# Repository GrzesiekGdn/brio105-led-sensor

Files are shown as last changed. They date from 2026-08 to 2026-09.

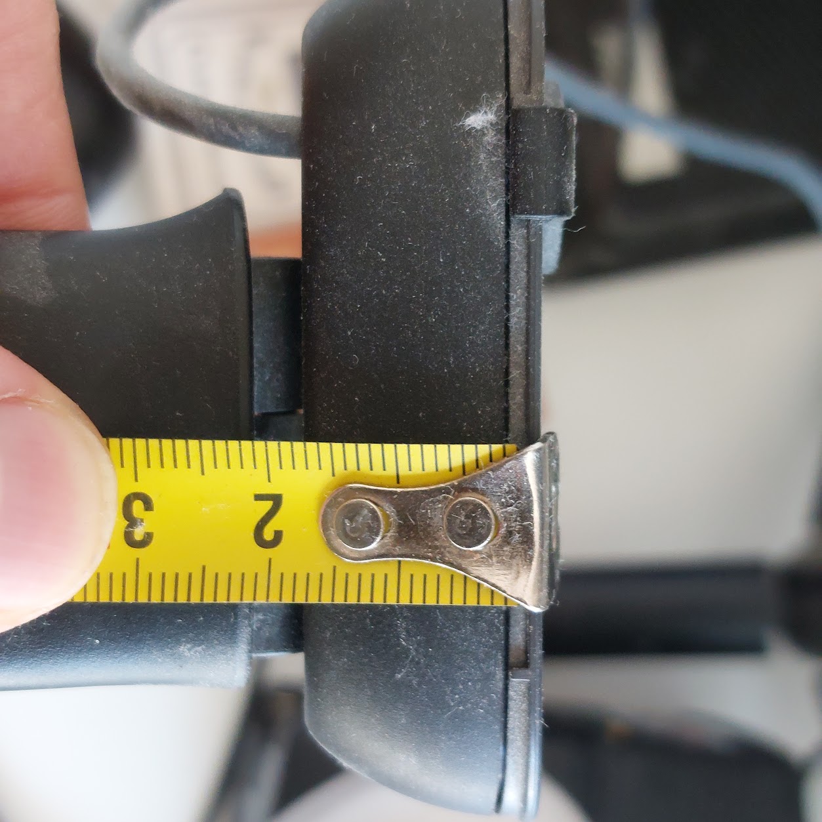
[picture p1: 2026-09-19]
hardware/clip/photos/20260829_162636.jpg

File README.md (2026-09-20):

# brio105-led-sensor

A 3D-printable clip and sensor pod that detect when a **Logitech Brio 105** webcam is in use — by *watching the camera's own activity LED*, not by asking the operating system.

---

## 🎯 Why

The obvious way to know whether your webcam is running is to ask the OS. That is what
[micam-watcher](https://github.com/GrzesiekGdn/micam-watcher) does, and if you can install
your own software on the machine, it is the better answer — see
[Alternative](#-alternative-if-you-can-install-software) below.

But on a **corporate / locked-down machine** you often cannot:

- no admin rights, no installing a background service
- no writing to the registry, no systemd user units
- endpoint protection that flags anything watching `/dev/video*` or camera registry keys
- and it may simply be against your employer's IT policy

The camera itself has no such restriction. Every Brio 105 lights a small LED whenever the
sensor is streaming — that signal is generated by the camera's own firmware, it is always
correct, and reading it requires touching nothing on the host at all.

So: clip a phototransistor over that LED, shroud it from ambient light, and read it with a
microcontroller that has no connection to the work machine whatsoever. The corporate laptop
never knows the sensor exists — no software installed, no policy violated, no privileged
access needed. It works with any camera and any OS, since the only thing being observed is
a lamp.

Typical use: turn on a "busy" light outside the room, or set a Home Assistant presence flag,
while you are on a call.

---

## 📐 Where the camera geometry came from

The parts have to fit the camera closely — a shroud that leaks ambient light is useless — so
the design is built on a real mesh of the camera, not on guesswork.

1. **No public CAD model exists** for the Brio 105. GrabCAD, STLFinder and Printables only
   carry mounts for other Brio models, and Logitech publishes no CAD for this one.
2. **Logitech's own product page does** ship a 3D model, though — the *"view in your room"* /
   AR preview that lets you rotate the webcam in the browser. That viewer loads a plain glTF
   binary asset, served from Logitech's CDN:

   ```
   https://resource.logitech.com/content/dam/logitech/en/ar-models/webcams/brio-100/brio-100-graphite-webcams-ar-360.glb
   ```

   (there is a matching `…-usdz-360.usdz` for iOS AR).
3. **The `.glb` was parsed by hand.** No mesh tooling was available in the environment
   (`trimesh`, `pygltflib`, Blender, assimp — none installable), so the container was
   unpacked directly with stdlib Python `struct`/`json`: read the glTF chunk table, walk the
   accessors/buffer views, pull the vertex and index arrays out of the binary chunk, and
   write the meshes back out as STL. Those exports are kept in [hardware/reference/](hardware/reference/):
   - `brio100-camera-head.stl` — the camera body itself
   - `brio100-monitor-clip.stl` — the monitor hanger, kept for context
4. **The mesh was measured by rasterization.** Again with no CAD library available, the STL
   was rendered into depth-map slices with a small custom Z-buffer renderer (Python + PIL)
   and scanned for features: the lens shows up as a ~10 mm circular recess at
   `(X=-15.8, Y=31.0)`, and the front/back faces around the LED are genuinely flat and
   parallel, ~17.9 mm apart. Those coordinates are what the `.scad` files are built from.
5. **Cross-checked against the physical camera** with a tape measure — bezel diameter, LED
   offset from the lens, housing depth. The mesh numbers and the hand measurements agree —
   except the first housing-depth reading, which came out about 1 mm short (see
   [Clip versions](#-clip-versions)).

You can see the fit yourself: open [hardware/clip/brio105-sensor-clip-v1.2.scad](hardware/clip/brio105-sensor-clip-v1.2.scad) in
OpenSCAD with `show_reference = true` and the reference mesh is `import()`-ed in ghost mode,
in the same coordinate frame, with the clip sitting on it.

### ⚠️ The one unverified assumption

The AR asset Logitech publishes is for the **Brio 100**, not the **105** — no Brio 105 AR or
CAD model could be found anywhere. Product photos strongly suggest the two share a housing
and mould, but this has **not** been confirmed. Check a printed part against your real Brio
105 before trusting the fit. Other open points are listed under
`STILL UNVERIFIED` in the `.scad` header.

---

## 📦 What is here

| File | What it is |
|---|---|
| `hardware/clip/` | The spring clip ("hairpin" style) that grips the flat front/back faces beside the LED — v1.2 (latest), v1.1 and v1.0, each `.scad` + `.stl`, plus the tape-measure photo the fit is based on. See its [README](hardware/clip/README.md) |
| `hardware/enclosure/` | Desk enclosure for the Seeed XIAO ESP32-C6 — snap-together tray and lid, holding the board, the 10k load resistor and the sensor-cable junction. Tray and lid as separate STLs; `part = "both"` in the `.scad` puts them on one plate. Also holds the XIAO reference model, `include`-ed as a ghost preview. See its [README](hardware/enclosure/README.md) |
| `hardware/pod/` | Alternative attachment: a magnetic sensor pod plus a stick-on anchor. Holds the TEPT4400 and acts as the light shroud. Rotationally keyed so it can only re-attach the right way round. |
| `hardware/reference/` | The STL meshes extracted from Logitech's AR asset (reference only — not printable parts) |
| `hardware/wiring/` | [Wiring and first tests](hardware/wiring/README.md) — the circuit, the two wiring layouts and the no-solder tests for the board, with the drawings in `hardware/wiring/img/` |
| `firmware/` | [Toolchain and tests](firmware/README.md) — what to install, how to run the three board tests, and where the Arduino functions come from |

**Sensor:** TEPT4400 phototransistor. **Print:** matte black PETG or ABS — glossy filament
reflects stray light down the tunnel and defeats the shroud. Per-part print notes are in each
`.scad` header.

---

## 🧬 Clip versions

Three versions live in [hardware/clip/](hardware/clip/README.md). They are geometrically
close, but they reach their fit in different ways, and v1.2 rebuilt the spring so the grip no
longer depends on the exact housing thickness — the earlier two flipped between *cracks on
fitting* and *falls off* with half a millimetre of error.

Prints of v1.1 and v1.2 are on order for a test fit; neither is confirmed yet. The clip's own
README has the full comparison and the print orientation, which matters more than the
material on this part.

---

## 🧰 Controller enclosure

The clip holds the phototransistor on the camera; the other end of the cable lives in a
free-standing desk box — a bare XIAO ESP32-C6, the 10k load resistor and the cable junction,
with USB-C plugged in for power. Two snap-together printed parts, built on Seeed's own KiCad
geometry rather than on a published drawing, since their wiki and datasheet disagree about the
board size.

See [hardware/enclosure/](hardware/enclosure/README.md), and
[hardware/wiring/](hardware/wiring/README.md) for what goes inside it.

---

## 🗺️ Roadmap

- [x] **1. Reference geometry** — extract and measure the camera model
- [ ] **2. Clip** — prints of v1.1 and v1.2 ordered; test-fit both on the real camera, keep
      the better one, dial in the spring interference
- [ ] **3. Phototransistor** — mount the TEPT4400 in the clip/pod, wire it to a Seeed XIAO
      ESP32-C6 ([wiring and first tests](hardware/wiring/README.md)) in its
      [enclosure](#-controller-enclosure),
      calibrate the threshold that separates "LED on" from ambient light
- [ ] **4. Software** — firmware that debounces the reading and sends the state to
      [Home Assistant](https://www.home-assistant.io/) over Zigbee (built into the XIAO ESP32-C6)
      or an HTTP webhook / MQTT, so it can drive an automation: a busy light, a lamp, a
      presence flag

---

## 🔌 Alternative: if you *can* install software

If the machine is yours, skip the hardware entirely.
**[micam-watcher](https://github.com/GrzesiekGdn/micam-watcher)** is a small cross-platform Go
service that detects camera *and* microphone activity from the OS itself — `lsof` on
`/dev/video*` and `pactl` on Linux, registry keys on Windows — and POSTs to the same kind of
Home Assistant webhook. No printing, no soldering, and it covers the microphone too, which a
camera LED cannot tell you about.

| | this project | micam-watcher |
|---|---|---|
| Needs software on the monitored machine | no | yes |
| Works on a locked-down / corporate machine | yes | usually not |
| Detects camera | yes | yes |
| Detects microphone | no | yes |
| Camera / OS specific | fits the Brio 105 housing | Linux & Windows |
| Effort | print, wire, calibrate | install a service |

---

## 📄 License

Copyright © 2026 Grzegorz Danowski. Two licenses, one per medium:

| What | License | |
|---|---|---|
| **Hardware designs** — `.scad`, `.stl`, `.3mf` | [CC-BY-SA 4.0](LICENSE) | Remix and sell them freely, including commercially — but credit this project and release your modified designs under the same license. |
| **Software** — future Arduino firmware and tooling | [MIT](LICENSE-CODE) | Do anything you like, just keep the copyright notice. |

The meshes in [hardware/reference/](hardware/reference/) are **not covered by either** — they are extracted from
Logitech's own published AR asset and remain Logitech's. They are included solely as a
dimensional reference for checking fit, and are not printable parts.

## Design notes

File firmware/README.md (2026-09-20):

# Firmware

Nothing final lives here yet. The sketches in [`tests/`](tests/) exist to prove the XIAO
ESP32-C6 works — and that it isn't faulty — before anything gets soldered. The real firmware
(read the sensor, debounce it, report to Home Assistant over Zigbee) is roadmap step 4.

The wiring and what each test proves are in
[hardware/wiring/](../hardware/wiring/README.md). This page is about the toolchain: what to
install, how to run the sketches, and where the functions in them come from.

---

## What to install

Either route installs the same package. The sketches here were compiled and run against
**esp32 core 3.3.12**.

### Arduino IDE 2

1. Install the IDE from [arduino.cc](https://www.arduino.cc/en/software).
2. **Tools → Board → Boards Manager**, search `esp32`, install **esp32 by Espressif
   Systems**, version **3.0 or newer**. Version 2.x does not know the C6. If it isn't listed,
   add this under **File → Preferences → Additional boards manager URLs**:
   ```
   https://raw.githubusercontent.com/espressif/arduino-esp32/gh-pages/package_esp32_index.json
   ```
3. **Tools → Board → esp32 → XIAO_ESP32C6**
4. **Tools → Port → /dev/ttyACM0**
5. Open a sketch, click **Upload**, then **Tools → Serial Monitor** at **115200**.

On Linux your user must be in the `dialout` group to open the port:

```sh
sudo usermod -aG dialout $USER     # then log out and back in
```

### arduino-cli

Same package, no IDE:

```sh
arduino-cli core update-index \
  --additional-urls https://raw.githubusercontent.com/espressif/arduino-esp32/gh-pages/package_esp32_index.json
arduino-cli core install esp32:esp32@3.3.12

# compile only - needs no board attached
arduino-cli compile -b esp32:esp32:XIAO_ESP32C6 firmware/tests/test2_alive

# compile and upload
arduino-cli compile -u -p /dev/ttyACM0 -b esp32:esp32:XIAO_ESP32C6 firmware/tests/test2_alive

# watch the output
arduino-cli monitor -p /dev/ttyACM0 -c baudrate=115200
```

---

## Running the tests

Upload one, watch the serial output, move on. Full procedure, expected results and the
keep-or-return table are in [hardware/wiring/](../hardware/wiring/README.md).

| Sketch | What it proves | What a working board printed |
|---|---|---|
| [`tests/test2_alive`](tests/test2_alive/test2_alive.ino) | Uploading works; processor, flash and USB messages work | `alive \| ESP32-C6 rev 2 \| 160 MHz \| flash 4 MB \| uptime 7 s`, and the yellow LED blinks |
| [`tests/test3_radio`](tests/test3_radio/test3_radio.ino) | The 2.4 GHz radio and antenna work — the same ones Zigbee uses | `3 networks found`, nearest at `-62 dBm` |
| [`tests/test4_adc`](tests/test4_adc/test4_adc.ino) | The analogue input the sensor will use (A0) works | `raw 676 586 mV` floating; ≈0 wired to GND, ≈4095 wired to 3V3 |

If an upload fails, put the board in download mode: hold **B** (BOOT), tap **R** (RESET),
release **B**, upload again, then tap **R** to run.

---

## Where do these functions come from?

A fair question, because an `.ino` file has almost no `#include` lines and still calls
`pinMode` and `Serial`. Three things are happening.

**1. The `.ino` is not quite C++ yet.** Before compiling, the IDE (or arduino-cli)
concatenates the sketch, adds `#include <Arduino.h>` at the top, and generates forward
declarations for your functions — which is why `loop()` can call a function defined below it.
The result is an ordinary `.cpp`.

**2. There is a `main()`, you just don't write it.** The core provides it. Simplified, it
calls `setup()` once and then `loop()` forever. On the ESP32 that loop runs inside a FreeRTOS
task, so `delay()` yields to the scheduler rather than burning cycles — which matters later,
when Wi-Fi or Zigbee needs time of its own.

**3. `Arduino.h` pulls in the rest.** On this core it includes `esp32-hal.h`,
`HardwareSerial.h` and `Esp.h`, and those bring everything the sketches use except `WiFi`:

| What the sketch calls | Where it is declared | `#include` needed? |
|---|---|---|
| `pinMode`, `digitalWrite`, `HIGH`, `LOW`, `OUTPUT` | `cores/esp32/esp32-hal-gpio.h` | no |
| `delay`, `millis` | `cores/esp32/esp32-hal.h` | no |
| `analogRead`, `analogReadMilliVolts` | `cores/esp32/esp32-hal-adc.h` | no |
| `Serial`, `Serial.begin`, `.println`, `.printf` | `cores/esp32/HardwareSerial.h` | no |
| `ESP.getChipModel()`, `.getFlashChipSize()` … | `cores/esp32/Esp.h` | no |
| `WiFi.scanNetworks()`, `WiFi.SSID(i)` … | `libraries/WiFi/src/WiFi.h` | **yes** — `#include <WiFi.h>` |

On this machine that is
`~/.arduino15/packages/esp32/hardware/esp32/3.3.12/…` — worth opening if you want to see how
thin most of these wrappers are.

### Two details specific to this board

**`Serial` is not a serial port here.** `HardwareSerial.h` contains:

```cpp
#define Serial HWCDCSerial    // when the board is built with cdc_on_boot=1
```

`XIAO_ESP32C6` sets `build.cdc_on_boot=1` by default, so `Serial` is the USB connection built
into the chip, not a UART on pins D6/D7. That is why the messages arrive over the same cable
that powers and flashes the board, and why the baud rate you pick is irrelevant — USB has no
baud rate. The Serial Monitor still asks for one; anything works.

**Arduino here is a layer, not the bottom.** `arduino-esp32` 3.x sits on top of Espressif's
own SDK, ESP-IDF 5.x. `analogRead` is a wrapper around the IDF ADC driver, `WiFi` around
`esp_wifi`. When Arduino doesn't expose something — precise ADC calibration, or Zigbee — you
can call IDF functions directly from the same sketch, because it is all one binary.

### Which of these are "libraries"?

Only one, strictly. `WiFi` is a library: a folder under `libraries/` in the core, with its own
`src/`, and it needs an `#include`. Everything else — `pinMode`, `delay`, `Serial`, `ESP` — is
the **core** itself, compiled into every sketch whether you use it or not. Nothing here comes
from the Library Manager, and these three sketches install no third-party dependencies at all.

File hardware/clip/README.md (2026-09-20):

# Camera clip

A spring clip ("hairpin" style) that grips the flat front and back faces beside the Brio 105's
activity LED and holds the TEPT4400 against it. Front and back are parallel there, so it
clamps by flexing, not by hooking a corner.

| File | What it is |
|---|---|
| `brio105-sensor-clip-v1.2.scad` / `.stl` | **Latest.** |
| `brio105-sensor-clip-v1.1.scad` / `.stl` | Earlier version, to be test-fitted against v1.2 |
| `brio105-sensor-clip-v1.0.scad` / `.stl` | First version, kept for comparison |
| `photos/` | Tape-measure photo of the housing depth that v1.2's fit is based on |

Open any version in OpenSCAD with `show_reference = true` and the camera mesh from
[`../reference/`](../reference/) is `import()`-ed in ghost mode, in the same coordinate frame,
with the clip sitting on it.

---

## Versions

All three share the same coordinate frame, lens and LED positions, and TEPT4400 bore, so
they are directly comparable in OpenSCAD.

> **Not yet tested.** Prints of v1.1 and v1.2 have been ordered for a test fit on the real
> Brio 105. Until they arrive and have been tried, neither is confirmed — this section will
> name the one that fits best.

| Version | Relaxed jaw gap | What changed |
|---|---|---|
| **v1.0** — proposed by Claude | 17.3 mm | First design, built on the reference mesh: 17.9 mm housing minus 0.6 mm interference. 12 mm tall jaws. |
| **v1.1** — revised with ChatGPT | 17.3 mm | Jaws raised to 14 mm. Fit rebased on a tape measurement of the real camera: 17.0 mm plus 0.3 mm clearance. Same gap as v1.0, opposite reasoning — v1.0 meant it to grip, v1.1 to slide on freely. |
| **v1.2** — also by Claude | 16.2 mm | Spring redesigned so the fit no longer depends on the exact housing thickness. |

**Why v1.2 exists.** v1.0 and v1.1 are geometrically nearly the same part, and share two
problems:

- **The spring was not a spring.** The back jaw wrapped the camera's rounded end, which left
  the "bridge" as a solid block and put all the flex in a stiff 2.5 mm jaw (~48 N/mm). A
  ±0.5 mm error in housing thickness flipped it between *cracks on fitting* and *falls off*.
  v1.2 uses a flat back jaw and makes a thin 1.5 mm bridge the flexure (~3.3 N/mm), so it
  holds across the whole plausible range of 17.0–18.6 mm without over-stressing.
- **The 17.0 mm reading was probably ~1 mm short.** The tape's end hook has about 1 mm of
  slide in its rivet slot. Measured off the photo in [`photos/`](photos/), the housing is
  ~18.2 mm — consistent with the reference mesh's 17.86 mm.

v1.2 also moves the jaw's near edge 0.6 mm back from the lens rim (v1.0/v1.1 sat just over
it), lets only contact ribs touch the housing, and adds a 5 × 3 mm funnel in front of the
sensor, so the LED can be off its assumed position by ±2 mm along the bar and ±1.5 mm
vertically and still be seen.

---

## Printing

**Orientation matters more than material here.** Lay the C-shape flat on the bed as a
17 × 27 mm footprint and build 14 mm upward — that is the model's **Y axis vertical**. The
whole flexure is then one constant cross-section: no supports, no bridging, and the bending
stress runs along the extrusion paths instead of across layer boundaries. The obvious
alternative, bore pointing up, puts the bridge's tensile stress normal to the layers, which
is how a spring like this fails months later.

Suggested: 4 perimeters, 40%+ infill, and a brim for the thin first-layer outline. Use matte
black filament — glossy reflects stray light down the tunnel and defeats the shroud. v1.2's
header argues for PLA here, as the stiffest common option; PETG works but creeps more under
sustained load.

The full rationale, the measurements behind every number, and a batch of test prints for the
two remaining unknowns are in the `.scad` headers.

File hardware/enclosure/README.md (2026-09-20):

# Controller enclosure

The clip or the pod holds the phototransistor on the camera; the other end of the cable has
to live somewhere too. This is a free-standing desk box for that end: a bare XIAO ESP32-C6,
the single 10k load resistor for the TEPT4400, and the junction where the sensor cable is
soldered on. USB-C stays plugged in for power, and the onboard ceramic antenna radiates
through the plastic — so nothing but the sensor cable leaves the box.

| File | What it is |
|---|---|
| `xiao-esp32c6-enclosure-v1.scad` | The enclosure. `part = "tray"`, `"lid"` or `"both"` — `"both"` puts them on one plate |
| `xiao-esp32c6-enclosure-v1-tray.stl` / `-lid.stl` | The two printed parts |
| `xiao-esp32c6-board.scad` | Reference model of the XIAO itself, `include`-ed as a ghost preview — not a printable part |

It is built the same way as the clip: not on a published drawing, but on the real geometry.
Seeed's wiki and their own datasheet disagree about the board size (17.8 vs 17.5 mm), and
neither publishes PCB thickness, component heights or LED positions, so
[`xiao-esp32c6-board.scad`](xiao-esp32c6-board.scad) is generated straight from Seeed's KiCad
PCB file instead. Open the enclosure in OpenSCAD with `show_board = true` and the board sits
in the box in its real position, the same trick as `show_reference` on the clip.

> **Not yet tested.** The tray and lid went to the print shop in the same order as the v1.1
> and v1.2 camera clips, so they arrive together and can be test-fitted in one go.

---

## Printing

Tray open side up, lid top face **down**. Neither needs support. PETG is preferred over PLA:
the snap arms work at about 1.6 % strain, which PLA survives but does not forgive.

They snap together with four full-depth cantilever arms — no glue, opened again with a
fingernail or a spudger at the pry notch. The activity LED shows through a light bar: a blind
pocket that leaves a 0.5 mm skin, so the lid is an unbroken surface until the LED lights up.

After a CGAL render (F6), `Volumes` should be **2** for a tray or lid on its own and **3** for
both parts together — that is the solid(s) plus the outside. A larger number means a feature
has come loose as a separate body. The `.scad` header carries the same treatment for the
snap-arm strain budget: change the wall, floor or plug clearances and re-read the strain
figure it echoes.

---

## Wiring

What goes inside the box — the resistor, the junction and the two-wire cable to the sensor —
is in [hardware/wiring/](../wiring/README.md), together with the tests that check the XIAO
itself before anything is soldered.

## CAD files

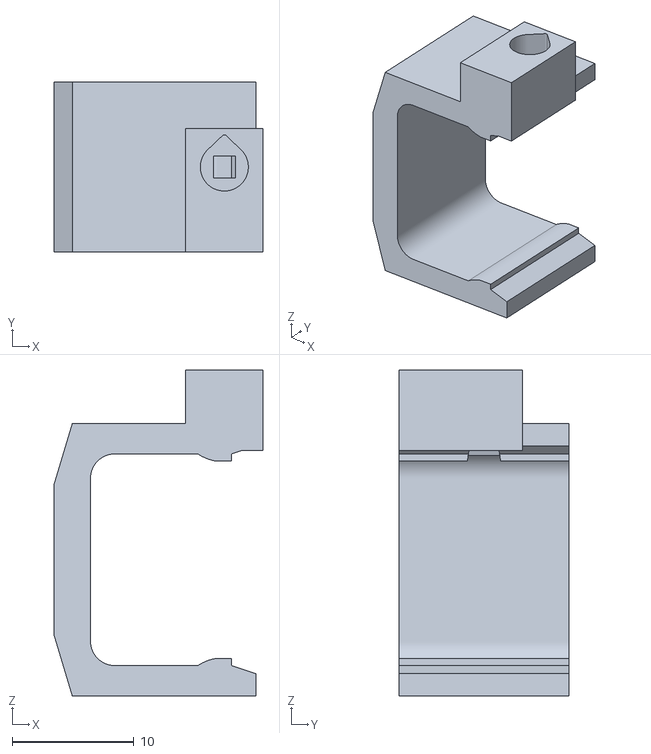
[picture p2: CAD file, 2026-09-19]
hardware/clip/brio105-sensor-clip-v1.2.stl
17.2 x 14.0 x 26.8

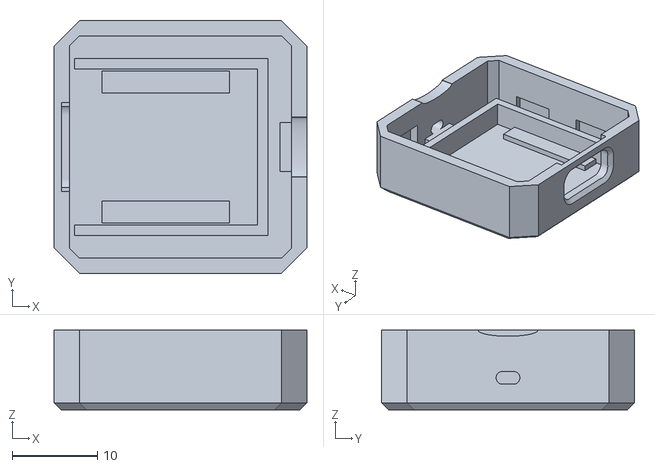
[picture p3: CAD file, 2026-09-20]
hardware/enclosure/xiao-esp32c6-enclosure-v1-tray.stl
29.8 x 29.8 x 9.35

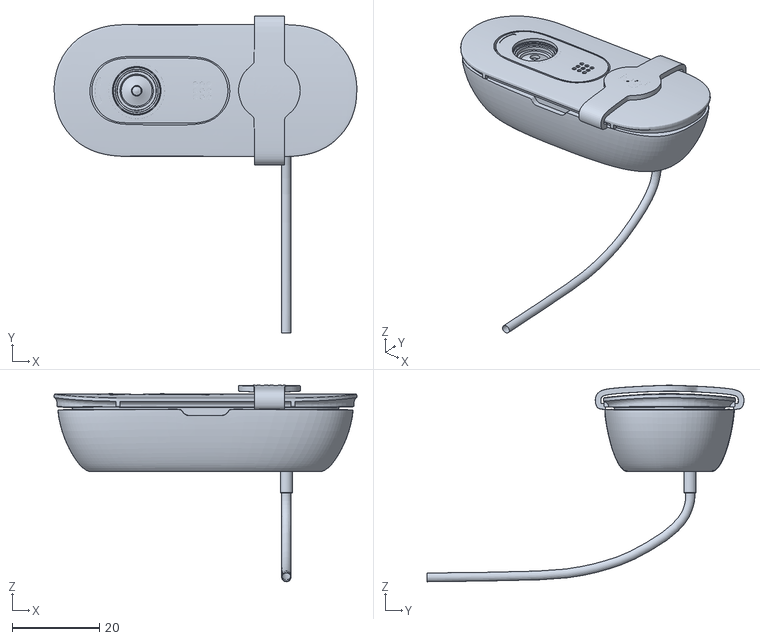
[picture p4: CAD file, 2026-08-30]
hardware/reference/brio100-camera-head.stl
69.5 x 72.8 x 45.1

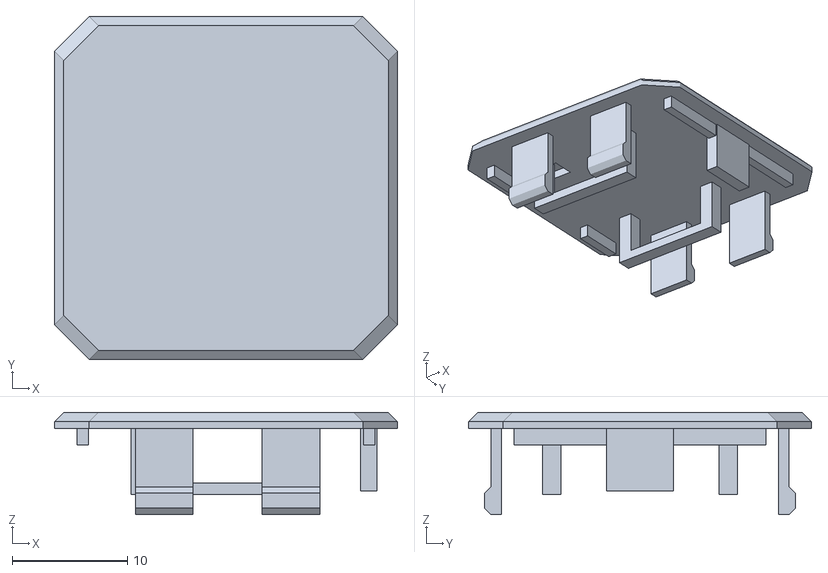
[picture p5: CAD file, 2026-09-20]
hardware/enclosure/xiao-esp32c6-enclosure-v1-lid.stl
29.8 x 29.8 x 8.85

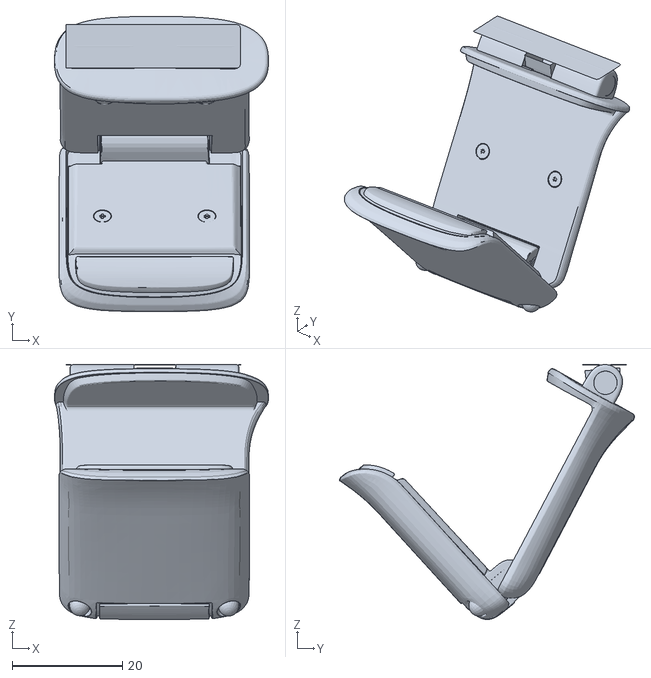
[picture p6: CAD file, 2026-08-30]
hardware/reference/brio100-monitor-clip.stl
38.9 x 53.6 x 46.3

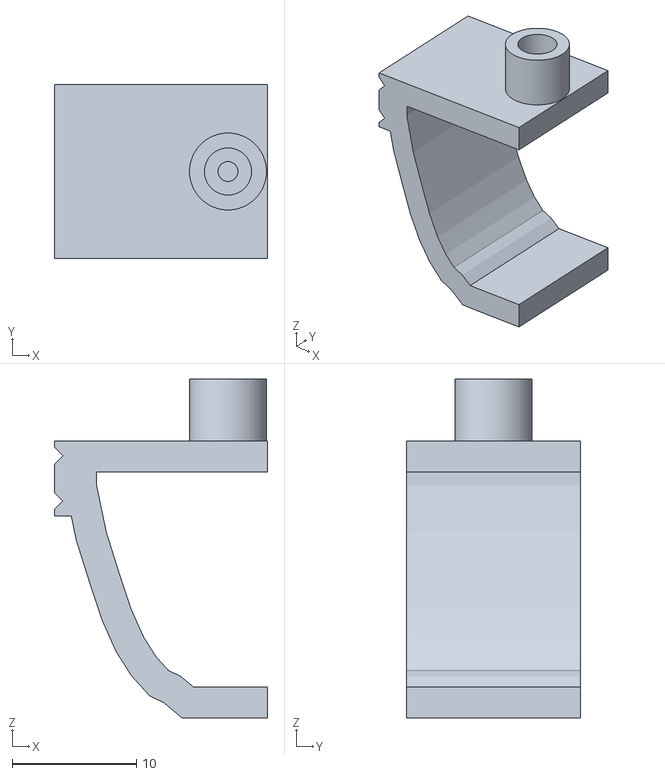
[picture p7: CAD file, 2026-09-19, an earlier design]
hardware/clip/brio105-sensor-clip-v1.1.stl
17.2 x 14.0 x 27.3

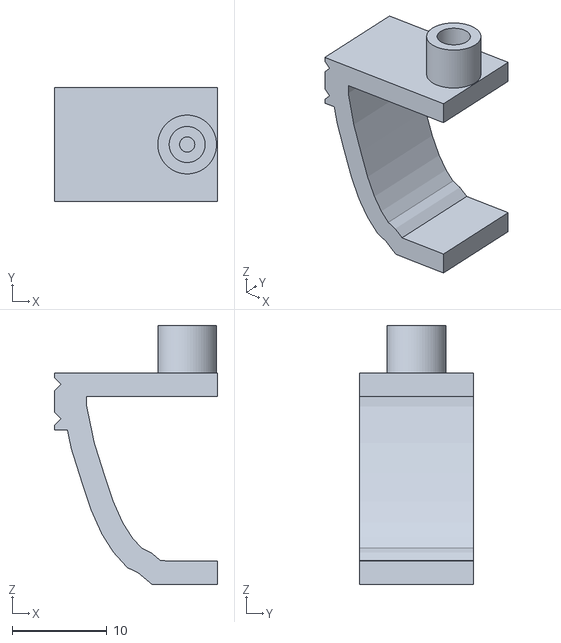
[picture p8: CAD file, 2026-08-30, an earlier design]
hardware/clip/brio105-sensor-clip-v1.0.stl
17.2 x 12.0 x 27.3

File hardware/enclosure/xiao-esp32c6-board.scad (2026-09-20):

// ============================================================
// XIAO ESP32-C6 REFERENCE BOARD MODEL
//
// NOT a downloaded mesh. Seeed only publish their 3D model via GrabCAD,
// which needs a login, so this is generated directly from their own
// KiCad design files instead:
//   XIAO_ESP32_C6_v1.0_SCH&PCB_260114.zip -> "XIAO ESP32 C6.kicad_pcb"
//   (linked from wiki.seeedstudio.com/xiao_esp32c6_getting_started)
// For fitting a case that is better than a mesh: it gives the
// authoritative position of every part, so clearances can be checked by
// intersection instead of by eye.
//
// EXACT, straight out of the PCB file:
//   - outline 20.955 x 17.780mm (Edge.Cuts) - so Seeed's wiki figure of
//     17.8 is right and their datasheet's 17.5 is wrong
//   - thickness 1.6mm (board stackup)
//   - X, Y, rotation and pad/courtyard footprint of all 81 parts
//   - every part is on the front. The underside really is flat, which is
//     what lets the tray sit the board on an 0.8mm standoff.
// INFERRED:
//   - part HEIGHTS. KiCad stores no Z. Taken from footprint names that
//     state one (ANT2P-5.2x2x1.1MM -> 1.1) and from package convention
//     otherwise (0402 -> 0.5, QFN -> 0.9, USB-C -> 3.26). Treat Z as
//     indicative and X/Y as measured.
//   - XY extents are the pad + courtyard + fab envelope, so for most
//     parts they are slightly larger than the plastic body. That is the
//     useful direction to err.
//   - USB1 is the exception and is hand-set from its COURTYARD, X
//     15.15..22.55 by Y 4.29..13.49. That courtyard is 7.40 deep against
//     a 7.35mm body, i.e. drawn on the body with no margin, so it is the
//     honest outline. Note what it means: the front face sits at 22.55
//     against a board edge at 20.955, so the receptacle OVERHANGS the
//     board by 1.60mm. Any case that pushes the board up to the wall has
//     to make room for that. Its F.Fab outline is not used - that is the
//     plug keepout, floating 1.2mm off the board edge.
//
// FRAME: origin at the board corner, X 0..20.955 with the USB-C end at
// HIGH X, Y 0..17.780, Z 0 at the underside.
// ============================================================

pcb_len   = 20.955;
pcb_wid   = 17.780;
pcb_thick = 1.600;
pcb_r     = 1.905;   // corner radius, from the four Edge.Cuts arcs:
                     // e.g. start(-10.414,-6.985) mid(-9.856,-8.332)
                     // end(-8.509,-8.89), centre (-8.509,-6.985)

// OPTIONAL REAL MESH
// ------------------
// Seeed's own 3D model exists but is not machine-downloadable: GrabCAD
// and Marathon-OS want a login and Printables returns 403 to anything but
// a browser. If you fetch one yourself, drop the file next to this one and
// put its name here - it is then used instead of the generated body, in
// the same frame. Nothing else needs to change.
//   https://www.printables.com/model/1338408-3d-model-for-seeed-studio-xiao-esp32c6  (Seeed's own)
//   https://grabcad.com/library/seeed-studio-xiao-esp32-c6-1
// A mesh will look better; it will not be more accurate about where the
// parts are, because this file's XY data IS the manufacturer's PCB file.
board_mesh = "";     // e.g. "xiao-esp32c6.stl"
mesh_rot   = [0,0,0];
mesh_off   = [0,0,0];

// Landmarks a case has to care about, board frame.
led_user_xy   = [16.540, 14.700];  // D4, yellow, GPIO15 - the useful one
led_charge_xy = [16.540,  3.020];  // CHG1, red, charge only
ufl_xy        = [ 1.406,  4.594];  // ANT2, U.FL external antenna
antenna_xy    = [ 1.153, 12.014];  // ANT1, onboard ceramic
usb_xy        = [15.148,  8.894];  // USB1, centred on the board width
usb_h         = 3.26;

// [ref, x0, y0, sx, sy, sz]  - x0,y0 is the low corner
parts = [
  ["ANT1", 0.153, 8.314, 2.000, 7.400, 1.10],
  ["ANT2", 0.126, 2.905, 3.121, 3.378, 1.00],
  ["C1", 6.450, 4.610, 0.813, 1.727, 0.50],
  ["C10", 9.304, 5.660, 0.305, 0.827, 0.30],
  ["C11", 10.874, 7.762, 0.305, 0.827, 0.30],
  ["C12", 8.458, 7.953, 0.305, 0.827, 0.30],
  ["C13", 4.680, 12.990, 0.813, 1.727, 0.50],
  ["C14", 4.882, 11.935, 0.789, 0.317, 0.30],
  ["C15", 4.872, 11.405, 0.789, 0.317, 0.30],
  ["C16", 4.994, 10.330, 0.305, 0.827, 0.30],
  ["C17", 4.882, 12.465, 0.789, 0.317, 0.30],
  ["C18", 4.282, 7.965, 0.789, 0.317, 0.30],
  ["C19", 7.084, 6.650, 0.305, 0.827, 0.30],
  ["C2", 9.962, 4.085, 0.789, 0.317, 0.30],
  ["C20", 11.937, 11.917, 0.789, 0.317, 0.30],
  ["C21", 12.802, 4.655, 0.789, 0.317, 0.30],
  ["C22", 12.822, 13.395, 0.789, 0.317, 0.30],
  ["C23", 4.434, 3.970, 0.305, 0.827, 0.30],
  ["C24", 4.492, 5.475, 0.789, 0.317, 0.30],
  ["C25", 6.544, 7.630, 0.305, 0.827, 0.30],
  ["C27", 1.004, 6.720, 0.305, 0.827, 0.30],
  ["C28", 2.484, 6.710, 0.305, 0.827, 0.30],
  ["C4", 5.153, 3.273, 1.727, 0.813, 0.50],
  ["C5", 7.214, 7.953, 0.305, 0.827, 0.30],
  ["C6", 11.692, 8.380, 0.789, 0.317, 0.30],
  ["C7", 11.692, 9.030, 0.789, 0.317, 0.30],
  ["C8", 12.303, 6.949, 0.305, 0.827, 0.30],
  ["C9", 11.812, 4.605, 0.789, 0.317, 0.30],
  ["CHG1", 15.665, 2.569, 1.775, 0.905, 0.50],
  ["D1", 10.957, 3.070, 0.762, 1.437, 0.60],
  ["D2", 12.837, 5.305, 0.762, 1.524, 0.50],
  ["D3", 11.363, 6.347, 0.762, 1.437, 0.60],
  ["D4", 15.665, 14.253, 1.775, 0.905, 0.50],
  ["K1", 19.072, 0.758, 1.600, 3.100, 0.53],
  ["K2", 19.072, 13.915, 1.600, 3.100, 0.53],
  ["L1", 7.115, 3.184, 2.743, 1.219, 0.85],
  ["L2", 5.494, 10.331, 0.305, 0.827, 0.30],
  ["L3", 4.984, 4.471, 0.305, 0.827, 0.30],
  ["L4", 5.452, 8.085, 0.789, 0.317, 0.30],
  ["L5", 1.502, 7.235, 0.789, 0.317, 0.30],
  ["Q1", 11.927, 3.332, 0.600, 1.000, 0.35],
  ["Q2", 10.050, 5.107, 1.075, 0.600, 0.35],
  ["Q3", 4.626, 8.524, 0.600, 1.000, 0.35],
  ["R1", 7.604, 6.651, 0.305, 0.827, 0.30],
  ["R10", 10.812, 4.605, 0.789, 0.317, 0.30],
  ["R11", 12.792, 3.125, 0.789, 0.317, 0.30],
  ["R12", 8.474, 6.822, 0.305, 0.827, 0.30],
  ["R13", 11.842, 14.405, 0.789, 0.317, 0.30],
  ["R14", 11.937, 11.409, 0.789, 0.317, 0.30],
  ["R15", 12.022, 9.910, 0.789, 0.317, 0.30],
  ["R16", 12.812, 4.135, 0.789, 0.317, 0.30],
  ["R17", 12.822, 13.905, 0.789, 0.317, 0.30],
  ["R18", 11.937, 12.435, 0.789, 0.317, 0.30],
  ["R19", 9.832, 5.835, 0.789, 0.317, 0.30],
  ["R20", 12.812, 3.635, 0.789, 0.317, 0.30],
  ["R21", 4.542, 9.735, 0.789, 0.317, 0.30],
  ["R22", 4.074, 9.301, 0.305, 0.827, 0.30],
  ["R23", 6.064, 6.651, 0.305, 0.827, 0.30],
  ["R24", 6.574, 6.651, 0.305, 0.827, 0.30],
  ["R25", 12.823, 14.415, 0.789, 0.317, 0.30],
  ["R3", 13.134, 9.981, 0.305, 0.827, 0.30],
  ["R6", 12.823, 7.001, 0.789, 0.317, 0.30],
  ["R7", 12.672, 8.380, 0.789, 0.317, 0.30],
  ["R8", 12.697, 9.030, 0.789, 0.317, 0.30],
  ["R9", 9.822, 4.605, 0.789, 0.317, 0.30],
  ["TP1", 10.925, 9.492, 1.143, 1.143, 0.60],
  ["TP10", 3.870, 9.141, 2.032, 1.016, 0.60],
  ["TP2", 10.868, 7.045, 1.143, 1.143, 0.60],
  ["TP3", 15.948, 9.585, 1.143, 1.143, 0.60],
  ["TP4", 13.408, 7.045, 1.143, 1.143, 0.60],
  ["TP5", 18.488, 7.045, 1.143, 1.143, 0.60],
  ["TP6", 13.408, 9.585, 1.143, 1.143, 0.60],
  ["TP7", 18.488, 9.585, 1.143, 1.143, 0.60],
  ["TP8", 15.948, 7.045, 1.143, 1.143, 0.60],
  ["TP9", 3.870, 6.601, 2.032, 1.016, 0.60],
  ["U1", 7.986, 4.994, 0.800, 1.200, 0.40],
  ["U3", 11.424, 5.135, 1.200, 0.900, 0.40],
  ["U4", 6.051, 9.021, 5.600, 5.600, 0.90],
  ["U5", 4.251, 6.030, 1.591, 1.669, 0.45],
  ["USB1", 15.150, 4.290, 7.400, 9.200, 3.26],  // see note - overhangs the edge
  ["X1", 9.078, 6.766, 1.550, 1.650, 1.20],
];

function part_named(n) = [for (p = parts) if (p[0] == n) p][0];

module xiao_parts() {
    for (p = parts)
        color(p[0] == "USB1" ? "#b0b0b0" : p[0] == "D4"   ? "#ffc400" :
              p[0] == "CHG1" ? "#d32f2f" : p[0] == "ANT2" ? "#90a4ae" :
              p[0] == "ANT1" ? "#5d4037" : "#37474f")
            translate([p[1], p[2], pcb_thick]) cube([p[3], p[4], p[5]]);
}

// True board outline: a rounded rectangle, not the plain cube an earlier
// version drew. The corners are radiused 1.905mm, so a square outline
// over-reports the board by up to 0.56mm at each corner.
module xiao_outline() {
    hull()
        for (sx = [0,1], sy = [0,1])
            translate([pcb_r + sx*(pcb_len - 2*pcb_r),
                       pcb_r + sy*(pcb_wid - 2*pcb_r)])
                circle(r = pcb_r);
}

module xiao_board(show_parts = true) {
    if (board_mesh != "") {
        translate(mesh_off) rotate(mesh_rot) import(board_mesh);
    } else {
        color("#1b5e20") linear_extrude(pcb_thick, convexity = 4)
            xiao_outline();
        if (show_parts) xiao_parts();
    }
}

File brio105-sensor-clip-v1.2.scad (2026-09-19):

// ============================================================
// END CLIP v1.2 - Logitech Brio 105 status-LED sensor mount
// Sensor: Vishay TEPT4400 phototransistor (3mm package)
//
// WHAT CHANGED vs v1.0 / v1.1, AND WHY
// ------------------------------------
// v1.0 and v1.1 are geometrically the same part (both produce inner_gap =
// 17.3mm; v1.1 only made the jaws 2mm taller and re-labelled the fit
// rationale). Two things in that shared architecture make a first-print
// success unlikely, and both are fixed here:
//
//  (1) THE SPRING WAS NOT A SPRING. In v1.0/v1.1 the back jaw is a
//      contoured shell that wraps the pod's end dome all the way up to
//      Z=46.07, which is only ~1mm short of the front jaw's inner face at
//      Z=47.1. The "bridge" joining them is therefore a 3 x 14 x 6mm
//      block - effectively rigid. All the compliance has to come from a
//      2.5mm-thick, 14mm-long jaw plate cantilevered off it:
//          k = 3EI/L^3 = 3 * 2500MPa * 18.2mm^4 / 14.2^3  ~= 48 N/mm
//      At v1.0's intended 0.6mm interference that is ~29N of clamping
//      force and ~28MPa of bending stress in the jaw root; at 1.5mm it is
//      ~72N and ~70MPa, i.e. past PLA's yield. Meanwhile v1.1's stated
//      +0.30mm clearance would give exactly 0N and no retention at all.
//      The design has no usable middle: a +-0.5mm error in the assumed
//      housing thickness flips it between "cannot be pushed on / cracks"
//      and "falls off". That is the opposite of what you want when the
//      first print has to work.
//      FIX: the back jaw is now a flat plate (it does not need to hug the
//      dome - see CLEARANCE below), so the bridge can be a full-height
//      1.5mm wall standing in the empty space past the pod's tip. The
//      bridge is now the flexure, and the spring rate drops to
//      ~3.3 N/mm at the gap. Same interference now gives a sane force and
//      ~18MPa peak stress, and the force varies gently with thickness
//      instead of switching on and off.
//
//  (2) THE ASSUMED HOUSING THICKNESS WAS PROBABLY A MISREAD. See
//      MEASUREMENT below. 17.0mm (v1.1) does not agree with either the
//      reference mesh or the tape-measure photo; ~18.2mm does. But
//      because of the fix above this part no longer has to be right about
//      it - see FIT WINDOW.
//
// Everything else that v1.0/v1.1 got right is kept: the coordinate frame,
// the LED/lens positions, the TEPT4400 bore sizing rationale, the
// collimating tunnel idea, and v1.1's 14mm jaw height (which turns out to
// match the housing's flat band Y=24..38 almost exactly - measured).
//
// MEASUREMENT (what the housing thickness actually is)
// ----------------------------------------------------
// Three independent numbers:
//   - reference/brio100-camera-head.stl, sampled in the Y=26..36 band:
//     17.86mm, dead constant from X=-27 to X=-18.
//   - photos/20260829_162636.jpg, measured off the image: the tape's 1mm
//     graduations run 19.98 px/mm (fitted over the 30mm..2mm span), the
//     pod's silhouette edges sit at x=460.0 and x=824.5 px, so the pod is
//     364.5px = 18.24mm. Reading the tape scale directly at each edge
//     gives 17.28mm and -1.03mm, i.e. 18.31mm - same answer.
//   - "17.0mm", the value v1.1 designs to.
// The photo also shows why 17.0 is low: the tape's printed zero
// extrapolates to x=804px, but the hook's inner face - the surface
// actually touching the camera - is at x=820. That ~1mm offset is the
// hook's rivet-slot travel. If the hook is not pulled taut against the
// edge it does not slide out to compensate, and the reading comes out
// ~1mm short. 17.3 read off the tape is ~18.3 in reality.
// So: nominal 18.2mm, and treat anything in 17.0..18.6 as possible.
//
// FIT WINDOW (why this part does not need the exact number)
// ---------------------------------------------------------
// Relaxed gap is 16.2mm, so the interference is (housing - 16.2):
//     housing 17.0mm -> 0.8mm -> ~2.6N clamp -> ~1.6N of friction
//     housing 18.2mm -> 2.0mm -> ~6.6N clamp -> ~4.0N of friction
//     housing 18.6mm -> 2.4mm -> ~7.9N clamp, ~18MPa peak stress
// (mu ~0.3, two faces.) The whole range holds, none of it over-stresses
// the part, and the worst case still needs under 1kgf to push on. The
// clip plus a 1m tail of thin wire is well under 10g, so even the
// pessimistic end has ~15x margin against sliding.
//
// CLEARANCE (why a flat back jaw is safe)
// ---------------------------------------
// Sampled from the reference mesh, Y=26..36 band: the back surface sits at
// Z=29.78 flat from X=-27 to X=-18, and only ever moves to HIGHER Z going
// outboard (30.65 at X=-28.5, 32.95 at X=-30.5, 44.71 at X=-34.5) as the
// end dome curls away. A flat jaw at Z<=29.78 is therefore never in the
// way - past X=-27 it simply hangs in free air, which is exactly what you
// want from a spring arm. Same on the front: the front face never exceeds
// Z=47.67 anywhere from the tip to the lens rim.
//
// LENS CLEARANCE (corrected)
// --------------------------
// v1.0/v1.1 put the jaw's near edge at X=-20.9 and called it "~0.4mm
// clear of the lens dip at -20.5 - TIGHT". Re-measured: the flush front
// face runs to X=-21.0 and the rim starts dropping immediately after
// (46.81 at X=-20.75, 46.43 at X=-20.25), so -20.9 is actually just over
// the edge. Near edge moved back to X=-21.5. It costs nothing here
// because contact is at the rib (X=-24.1), not at the jaw tip.
//
// COORDINATE SYSTEM: unchanged from v1.0/v1.1 and from the reference STL,
// so the mesh still import()s with zero transform.
//   X: along the camera bar. Mesh spans -34.76 .. +34.76.
//   Y: vertical on the camera body. Head spans 16.16 .. 46.03.
//   Z: depth. HIGH Z = front (lens side), LOW Z = back (hinge side).
//
// STILL UNVERIFIED - CHECK BEFORE PRINTING
// ----------------------------------------
//  - The reference mesh is Logitech's AR asset for the Brio *100*. No
//    Brio 105 model exists. Housings look identical in product photos;
//    unconfirmed. This is why the fit window above matters more than the
//    nominal.
//  - The LED position (X=-24.1, Y=31.0) comes from your tape reading
//    ("8-10mm from the lens centre, same height"), not from the mesh -
//    the LED is not a geometric feature in it. The funnel below is built
//    to absorb that: its mouth is a 5.0 x 3.0mm slot, so the LED can be
//    anywhere in X=-22.1..-27.1 and Y=29.5..32.5 and still be seen. Your
//    stated range maps to X=-23.8..-25.8, which sits inside that with
//    >1.3mm to spare on each side.
// ============================================================

$fn = 96;

// ---- measured camera geometry (mesh frame, mm) ----
lens_x   = -15.8;
lens_y   = 31.0;
led_x    = -24.1;   // from your tape measurement, not from the mesh
led_y    = 31.0;
front_z  = 47.67;   // flush front face at the LED (mesh)
back_z   = 29.78;   // flat back face (mesh, constant X=-27..-18)

// ---- fit ----
camera_thickness = 18.2;   // see MEASUREMENT. mesh 17.86, photo 18.24-18.31
interference     = 2.0;    // designed spring deflection at nominal
inner_gap        = camera_thickness - interference;   // 16.2mm relaxed

// If the printed clip is too stiff or too loose, change ONLY this:
//   too hard to push on  -> raise inner_gap (lower interference)
//   slides off / no grip -> lower inner_gap (raise interference)
// 0.4mm steps are a sensible increment (~1.3N of clamp force each).

// ---- clip body ----
near_margin  = 2.6;    // led_x -> jaw's lens-side edge, X=-21.5 (rim at -21.0)
far_margin   = 11.0;   // led_x -> jaw's tip-side edge, X=-35.1 (pod tip -34.76)
jaw_thick    = 2.5;    // jaw plate thickness - stiff on purpose, see rib below
jaw_height   = 14;     // along Y, centred on led_y -> Y=24..38, the housing's
                       // full-thickness flat band (>=17.6mm) measured from the
                       // mesh. v1.1's value, now confirmed rather than assumed.
relief       = 0.6;    // jaw inner faces stand off this far; only the ribs touch
bridge_thick = 1.5;    // THE FLEXURE. this number sets the spring rate.
bridge_flare = 1.5;    // extra thickness blended in at both bridge ends
bridge_flare_len = 5;  // over this much Z at each end
fillet_r     = 2.0;    // inside corners where the jaws meet the bridge
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

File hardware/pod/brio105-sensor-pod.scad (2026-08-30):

// ============================================================
// Camera-in-use LED sensor pod + magnetic anchor
// For: Logitech Brio 105, TEPT4400 phototransistor, 3x1mm magnets
//
// Two parts on one plate:
//   1) sensor_pod()     - holds the TEPT4400 + acts as the light shroud
//   2) magnet_anchor()  - sticks to the camera next to the LED
//
// MEASURED FROM THE ACTUAL CAMERA (tape measure + photos):
//   - LED is a thin arc, ~10-11mm from the camera's left edge (~1mm wide)
//   - Top of the LED arc is ~12mm from the camera's top edge
//   - Camera housing (front capsule) thickness/depth: 17mm
// These numbers are for placing the anchor by hand - they are NOT baked
// into the model, since the pod attaches via magnet, not a fixed clamp.
// Before printing: cut a ~14mm x 11mm rectangle out of paper/cardboard
// and hold it at that spot on the real camera to confirm it clears the
// lens and the housing's curved edge - cheap sanity check against a
// camera curvature I'm guessing at, not measuring directly.
//
// ROTATION KEYING
// A single round magnet-to-magnet joint has no rotational preference -
// the pod could spin on re-attachment and drift the tunnel off the LED.
// To prevent that, the pod/anchor footprint is deliberately asymmetric
// (a "fat end" toward the sensor bore, "thin end" toward the magnet) so
// the two parts can only mate in the correct orientation.
//
// PRINT NOTES
// - Material: matte black PETG or ABS. Glossy filament reflects stray
//   light down the tunnel and defeats the shroud.
// - Orientation: print both parts sitting on their front/adhesive face,
//   holes opening upward - no supports needed either part.
// - FDM holes print undersized - test-fit the TEPT4400 and the magnet
//   after printing; ream out by hand with a 3mm/3.2mm drill bit if tight.
// - The front rim is flat/rigid and won't perfectly match the camera's
//   slight curve. Stick a thin ring of adhesive foam weatherstrip tape
//   to the front rim before final placement - it conforms to the curve
//   and completes the light seal far better than bare plastic-on-plastic.
// - Mark the magnet's polarity with a marker dot before gluing into each
//   part, so pod and anchor always attract (not repel).
// ============================================================

$fn = 64; // smooth circles

// ---- measure-and-adjust before printing ----
tept_dome_d      = 3.0;   // TEPT4400 dome diameter (datasheet nominal)
tept_bore_d      = tept_dome_d + 0.4;   // add clearance
tept_bore_depth  = 5.0;   // dome + a bit of the leaded body

tunnel_d         = 1.6;   // narrowed from an earlier 2.0mm - the measured
                          // LED arc is only ~1mm wide, so a tighter
                          // tunnel improves contrast (trade-off: needs
                          // more careful alignment when placing the pod)
tunnel_len       = 2.5;   // longer = better ambient-light rejection,
                          // but must stay clear of the lens - keep short

magnet_d         = 3.2;   // 3mm magnet + clearance
magnet_len       = 1.3;   // 1mm magnet + a little glue gap

pod_wall         = 1.8;   // wall thickness around each hole
hole_gap         = 1.5;   // minimum plastic wall between the two holes
key_bump         = 2.0;   // extra radius on the sensor end only - this is
                          // what makes the footprint asymmetric

pod_len          = tept_bore_depth + tunnel_len;

// hole centers, offset along X so the two blind holes never intersect
hole_offset = tept_bore_d/2 + magnet_d/2 + hole_gap;
sensor_x = -hole_offset/2;
magnet_x =  hole_offset/2;

r_sensor_end = tept_bore_d/2 + pod_wall + key_bump; // "fat end"
r_magnet_end = magnet_d/2 + pod_wall;               // "thin end"

// ============================================================
module pod_footprint(r1, r2) {
    hull() {
        translate([sensor_x, 0]) circle(r = r1);
        translate([magnet_x, 0]) circle(r = r2);
    }
}

module sensor_pod() {
    difference() {
        linear_extrude(height = pod_len)
            pod_footprint(r_sensor_end, r_magnet_end);

        // sensor bore: wide dome pocket, opens at the BACK face (top)
        translate([sensor_x, 0, tunnel_len])
            cylinder(d = tept_bore_d, h = tept_bore_depth + 1);

        // narrow shroud tunnel, opens at the FRONT face (presses on camera)
        translate([sensor_x, 0, 0])
            cylinder(d = tunnel_d, h = tunnel_len + 0.5);

        // magnet pocket, opens at the BACK face, same side as the bore
        translate([magnet_x, 0, pod_len - magnet_len])
            cylinder(d = magnet_d, h = magnet_len + 0.5);
    }
}

module magnet_anchor() {
    anchor_thick = magnet_len + 1.2;
    difference() {
        linear_extrude(height = anchor_thick)
            pod_footprint(r_sensor_end, r_magnet_end);

        // magnet pocket at the same X position as the pod's magnet hole,
        // so the two parts only line up magnet-to-magnet when the fat
        // end (sensor side) of both point the same way
        translate([magnet_x, 0, anchor_thick - magnet_len])
            cylinder(d = magnet_d, h = magnet_len + 0.5);
    }
}

// ---- layout for printing ----
pod_total_len = hole_offset/2 + r_sensor_end + hole_offset/2 + r_magnet_end;

sensor_pod();
translate([pod_total_len + 5, 0, 0])
    magnet_anchor();

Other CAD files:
hardware/clip/brio105-sensor-clip-v1.2.scad
brio105-sensor-clip-v1.0.scad
brio105-sensor-clip-v1.1.scad
hardware/clip/brio105-sensor-clip-v1.0.scad
hardware/clip/brio105-sensor-clip-v1.1.scad
hardware/enclosure/xiao-esp32c6-enclosure-v1.scad

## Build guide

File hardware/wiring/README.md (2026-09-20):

# Wiring and first tests

How to connect the TEPT4400 to a **Seeed XIAO ESP32-C6**, why the circuit works, and how to
check that the XIAO is healthy before soldering anything.

| Part | Role |
|---|---|
| Seeed XIAO ESP32-C6 | Reads the sensor; later reports to Home Assistant over Zigbee |
| TEPT4400 phototransistor (3 mm, 570 nm) | Lets current through when light falls on it |
| 10 kΩ resistor, ¼ W | Turns that current into a voltage the XIAO can measure |
| Two-wire cable, red + black | From the board to the sensor on the camera |
| Two short wires (layout A only) | Inside the enclosure — blue and green in the drawings; any colours will do |

---

## How the circuit works

Schematic: the cable's red wire feeds the phototransistor's collector from 3V3; its black wire brings the emitter back to the junction with a 10 kΩ resistor to ground; that junction is wired to pin A0.

The phototransistor sits out on the camera, inside the dashed box: the two wires crossing that
box are your **red and black cable**, red carrying 3V3 to the C leg and black bringing the E leg
back. Light lets current flow from 3V3 down through the phototransistor and the resistor to GND.
The more current, the higher the voltage at the junction, and that voltage is what A0
measures: about 0 V in the dark, rising towards 3.3 V in bright light. The resistor is drawn
as a box, the European symbol; American drawings use a zigzag.

| Light on the sensor | What A0 reads (roughly) |
|---|---|
| Covered with a finger | close to 0 |
| Normal room light | somewhere in between — depends on the room |
| Phone torch right up close | high, possibly the maximum (4095 raw, ~3 V+) |

### What the resistor is actually for

The phototransistor does not produce a voltage. Light makes it **conduct current** — think of
it as a tap that light opens, wider in bright light, almost shut in the dark. The XIAO's
analogue input does the opposite: it **measures voltage**, and draws practically no current
itself. So there is nothing for it to read yet.

The resistor is the converter between the two, and the whole of it is Ohm's law:

```
voltage = current × resistance        V = I × R
```

Every microamp the phototransistor lets through has to pass down through the 10 kΩ on its way
to GND, and pushing current through a resistance produces a voltage across it. That voltage,
right at the junction, is what A0 reads:

| Current through the sensor | Voltage at A0 across 10 kΩ |
|---|---|
| 10 µA | 0.1 V |
| 100 µA | 1.0 V |
| 330 µA and above | 3.3 V — the ceiling; brighter light can't push it higher |

**What happens without it?**

- Wire the E leg straight to A0 and nowhere else, and no current can flow at all: there is no
  path to GND. The pin is left "floating" and reads drifting nonsense — exactly what test 4
  shows with nothing connected. It's the same reason a digital input needs a pull-up or
  pull-down: an input with no defined path to a known level reads noise.
- Wire the E leg straight to GND instead, and current flows happily, but the voltage at that
  point is 0 V no matter how bright the light. Nothing to measure.

The two parts together make a **voltage divider**: 3V3 at the top, GND at the bottom, and the
reading in the middle. What makes it useful here is that the upper half changes with light
while the lower half stays fixed.

**The value sets the sensitivity.** More ohms means more volts per microamp:

- **47 kΩ** — reacts to dim light, but saturates at 4095 as soon as the LED is bright
- **10 kΩ** — a sensible start for an LED a few millimetres away in a shroud
- **2.2 kΩ** — needs plenty of light to move, but won't saturate

10 kΩ is a starting point, not a fixed truth. If the shrouded reading turns out to sit at the
ceiling whether the LED is on or off, go down; if it barely moves, go up.

One thing you don't need to worry about: heat. At these currents the resistor dissipates
around a microwatt (`P = I² × R`). Your ¼ W part is roughly 250 000 times over-specified — the
wattage you buy is about physical size and handling, not about this circuit.

In the finished project the sensor sits against the camera's LED in a dark shroud, so the
reading jumps when the LED switches on. Where to put the "LED is on" threshold is roadmap
step 3.

---

## Two ways to wire it — same circuit

Both layouts use the same three board pins and a **two-wire cable** to the sensor. The only
difference is where the junction is. The board is seen from the top, USB-C socket up.

### Layout A — junction in a splice

Layout A: the cable's red wire from 3V3 to the C leg and its black wire from the E leg to the junction; a blue wire inside the enclosure runs from the junction to D0 and a green one from the resistor to GND.

The cable's two wires go out to the phototransistor: **red** from 3V3 to its C leg, and
**black** back from its E leg to the junction. There the black wire, the resistor and a short
wire to D0 are joined in one splice. Two wires stay inside the enclosure: **blue** from the junction to D0 and
**green** from the resistor to GND. Those are simply the colours drawn here — any colours
will do.

### Layout B — resistor straight on the board

Layout B: the resistor's legs go into D0 and GND; the cable runs red from 3V3 to C and black from D0 to E.

No splice, and no wires inside the enclosure at all. The resistor's legs go straight into the
**D0** and **GND** holes, and the cable's two wires go into **3V3** (red, to C) and **D0**
(black, to E). D0 holds two conductors, the resistor leg and the black wire, and that makes
the D0 hole itself the junction. The legs are long enough to fold the resistor out of the
way, but bare legs running over the board must be sleeved.

| | Layout A · splice | Layout B · on the board |
|---|---|---|
| Wires in the cable to the sensor | 2 | 2 |
| Board holes used | 3V3, GND, D0 | 3V3, GND, D0 |
| Conductors in the D0 hole | 1 | 2 — resistor leg + black cable wire |
| Loose splices to insulate | 1 three-way splice | none |
| Wires inside the enclosure | 2 — blue and green here | none — the resistor's own legs reach |

| Board pin | Where on the board | Layout A | Layout B |
|---|---|---|---|
| `3V3` | right side, 3rd from USB | cable red → C leg | cable red → C leg |
| `GND` | right side, 2nd from USB | green → resistor | resistor leg |
| `D0` (= A0) | left side, 1st from USB | blue → junction | resistor leg + cable black → E leg |

**In this cable, black is not ground.** It is the signal wire: it comes back from the
phototransistor's E leg and ends at D0. Ground is only needed inside the enclosure, where the
resistor's other end goes to the GND pin. Nothing in the two-wire cable connects to GND.

**Which leg is C and which is E?** The TEPT4400 datasheet's package drawing shows it. If
you're not sure, just try it: wire it one way and run test 5 below. If the reading doesn't
react to light, swap the two legs. The resistor limits the current to 0.33 mA, so the wrong
way round can't damage anything.

**Is it really 10 kΩ?** A four-band resistor reads *brown · black · orange · gold*. A
five-band one (often with a blue body) reads *brown · black · black · red · brown*.
Resistors work either way round.

> [!WARNING]
> **Three rules that protect the board**
> 1. **The sensor goes to 3V3, never to 5V.** Powered from 5V, the circuit can push more
>    than 3.3 V into A0, and that can permanently damage the pin. 5V and 3V3 are two pins
>    apart on the same side.
> 2. **Never connect 3V3 straight to GND.** They sit next to each other; a touching wire or
>    a solder blob between them is a short circuit. Check before you plug in.
> 3. **Change wires with the USB cable unplugged.** Connect first, then plug in.

---

## Testing the XIAO without soldering

Do these in order. Steps 1–4 need only a USB-C cable and one jumper wire, and together they
tell you whether the board works. Toolchain details — and where the functions in the sketches
come from — are in [firmware/](../../firmware/README.md).

> [!TIP]
> If the board is going into a slim enclosure, **don't solder the header pins** that come
> with it — they add several millimetres above and below the board. Solder the final wires
> straight into the holes instead.

### 0. One-time setup

- **Let your user talk to USB serial devices** (Debian/Ubuntu). Run this once, then log out
  and back in:
  ```sh
  sudo usermod -aG dialout $USER
  ```
- Install **Arduino IDE 2** from arduino.cc.
- **Tools → Board → Boards Manager**, search `esp32`, and install **esp32 by Espressif
  Systems**, version **3.0 or newer** — older versions don't know the C6. If it isn't listed,
  add this URL under **File → Preferences → Additional boards manager URLs**:
  ```
  https://raw.githubusercontent.com/espressif/arduino-esp32/gh-pages/package_esp32_index.json
  ```
- Choose **Tools → Board → esp32 → XIAO_ESP32C6**. **USB CDC On Boot** is *Enabled* by
  default on this board, which is what sends the board's messages up the USB cable — if the
  Serial Monitor stays empty, check that it hasn't been switched to *Disabled*.
- Use a USB-C cable that **carries data**. Many cables only charge: they light the board, but
  the computer never sees it.

### 1. Does the computer see it?

**Proves** that the chip gets power and its USB works. This is built into the chip itself, so
it works even if the board's program is broken, which makes it the most important test.

```sh
lsusb | grep -i 303a
ls /dev/ttyACM*
```

You should see:

```
Bus 001 Device 012: ID 303a:1001 Espressif USB JTAG/serial debug unit
/dev/ttyACM0
```

**If not:** try another cable first — that's the cause most of the time. Then another USB
port. Then *download mode*: hold the tiny **B** (BOOT) button beside the USB socket, plug the
cable in, and release. Still nothing after all three? The board is faulty.

A **red LED flickering or blinking** is normal. It's the battery-charge light, and with no
battery fitted it does that.

### 2. Can it run a program?

**Proves** that uploading works, and the processor, memory and USB messages all work.

Open [`firmware/tests/test2_alive`](../../firmware/tests/test2_alive/test2_alive.ino), pick
**Tools → Port → /dev/ttyACM0**, click **Upload**, then open **Tools → Serial Monitor** at
115200 baud. The yellow LED beside the USB socket blinks, and the monitor shows (the `rev`
number can be anything):

```
alive | ESP32-C6 rev 1 | 160 MHz | flash 4 MB | uptime 7 s
```

**If the upload fails:** put the board in download mode — hold **B**, tap **R** (RESET),
release **B** — and upload again; afterwards tap **R** to start the program. **If the LED
blinks but the monitor stays empty:** check *USB CDC On Boot → Enabled*, upload again, and
pick the port again. The board reconnects after an upload.

### 3. Does the radio work?

**Proves** that the 2.4 GHz radio and the antenna work. Wi-Fi and Zigbee share the same
radio and antenna on this chip, so finding your router here also covers the part of Zigbee
that can be broken in hardware.

Upload [`firmware/tests/test3_radio`](../../firmware/tests/test3_radio/test3_radio.ino). It only
listens and doesn't connect anywhere. Your own router a few metres away should show at around
−30 to −65 dBm:

```
scanning...
3 networks found
  YourNetwork                       -44 dBm  channel 6
  Neighbour_5G                      -78 dBm  channel 11
```

**If it finds 0 networks** while your phone, in the same spot, sees several: the radio or
antenna is faulty.

### 4. Can it measure a voltage?

**Proves** that the analogue input the sensor will use (A0) works. Upload
[`firmware/tests/test4_adc`](../../firmware/tests/test4_adc/test4_adc.ino); you need one jumper
wire.

- **Unplug USB.** Push the jumper wire's ends into the **D0** and **GND** holes, tilting each
  slightly so it presses against the metal ring. Plug in: the reading should be **about 0**.
- **Unplug,** move the GND end to **3V3**, plug in again: the reading should be **close to
  4095**, about 3000 mV or more.
- With nothing connected to D0 the numbers wander randomly. That's normal: an unconnected
  input "floats".

**If it reads 0 or 4095 no matter what,** check that the wire really touches the rings. If it
still does after that, the analogue input is faulty.

### 5. Optional: the real sensor, still without solder

**Proves** that the phototransistor and resistor work, and shows which leg is C. You need a
small breadboard.

- Push the header pins into the breadboard and **lay the XIAO on top of them without
  soldering**, pressing it down gently while you test.
- Wire it as in either layout above. On a breadboard layout B comes naturally: the resistor
  goes from the D0 row to the GND row. Run the test 4 program again, unchanged.
- Cover the sensor: the number drops. Shine a phone torch on it: it rises. No reaction at all?
  Swap the phototransistor's legs.

**If the readings jump when you touch the board,** that's the loose pin contact, not a faulty
XIAO.

---

## Keep it or send it back?

| What you see | What it means | Decision |
|---|---|---|
| Not in `lsusb` — with two data cables, two ports, and in download mode | dead board | return |
| Visible in `lsusb`, but uploading fails even in download mode | faulty board | return |
| Test 3 finds 0 networks while your phone sees them | radio or antenna fault | return |
| Test 4 reads the same fixed value whatever D0 touches | analogue input fault | return |
| Red LED flickers with no battery connected | normal charge-light behaviour | ignore |
| Tests 1–4 all pass | USB, processor, memory, radio and A0 all work | keep it |

---

## After the tests: solder the final connections

A wire or resistor leg pushed into a plated hole touches the metal ring only where it happens
to lean on it. Nothing springs it into place, the way a breadboard clip or a connector does.
That's fine for a few minutes of testing. Over weeks, a desk bump, a tug on the camera cable,
or a thin oxide layer on the copper turns it into a connection that opens and closes on its
own.

In this circuit every interruption looks like a real event. If GND breaks, A0 jumps high and
the LED seems *on*. If 3V3 breaks, A0 drops to zero and the LED seems *off*. If D0 breaks, the
pin floats and reads random numbers. Home Assistant would see the "busy" state flicker for no
reason, and no firmware can tell that apart from the real LED.

A solder joint doesn't move, so the only variation left is the analogue input's own small
noise, a few counts, which the firmware can average away. Soldering into plated through-holes
is also the easiest soldering there is.

**Zigbee comes next.** The XIAO can talk Zigbee, but Home Assistant also needs a Zigbee
*coordinator*, usually a small USB stick on the Home Assistant machine. The Arduino settings
for that (**Tools → Zigbee Mode → Zigbee ED (end device)** and a Zigbee partition scheme)
aren't needed for any of the tests above.

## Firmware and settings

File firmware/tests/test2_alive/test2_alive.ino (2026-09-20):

// Test 2 - is the board alive?
// Blinks the small yellow LED beside the USB socket and
// prints what the chip reports about itself, once a second.

const int LED_PIN = 15;   // the yellow "user" LED
bool ledOn = false;

void setup() {
  Serial.begin(115200);
  pinMode(LED_PIN, OUTPUT);
}

void loop() {
  ledOn = !ledOn;
  digitalWrite(LED_PIN, ledOn ? HIGH : LOW);   // on, off, on, off...

  Serial.printf("alive | %s rev %d | %lu MHz | flash %lu MB | uptime %lu s\n",
                ESP.getChipModel(), ESP.getChipRevision(),
                (unsigned long)ESP.getCpuFreqMHz(),
                (unsigned long)(ESP.getFlashChipSize() / (1024 * 1024)),
                millis() / 1000);
  delay(1000);
}

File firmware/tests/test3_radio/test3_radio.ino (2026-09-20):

// Test 3 - does the radio work?
// Lists the Wi-Fi networks around you. It only listens -
// it does not connect to anything.
#include <WiFi.h>

void setup() {
  Serial.begin(115200);
  WiFi.mode(WIFI_STA);
}

void loop() {
  Serial.println("scanning...");
  int n = WiFi.scanNetworks();
  Serial.printf("%d networks found\n", n);
  for (int i = 0; i < n; i++) {
    Serial.printf("  %-32s %4d dBm  channel %d\n",
                  WiFi.SSID(i).c_str(), WiFi.RSSI(i), WiFi.channel(i));
  }
  WiFi.scanDelete();
  delay(5000);
}

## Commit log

2026-09-19 Add clip v1.1 and v1.2, version the original as v1.0
    - Rename the original clip to brio105-sensor-clip-v1.0 (.scad/.stl);
    drop its .3mf.
    - Add v1.1 (revised with ChatGPT): 14mm jaws, fit rebased on a 17.0mm
    tape reading.
    - Add v1.2: flat back jaw with a 1.5mm bridge as the flexure, so the fit
    holds across a 17.0-18.6mm housing; lens-rim clearance corrected; LED
    funnel added.
    - Add the tape-measure photo that v1.2's housing-depth figure is taken
    from.
    - README: new "Clip versions" section describing the three versions and
    why v1.2 exists; v1.1 and v1.2 prints are ordered for a test fit, so
    neither is marked as confirmed yet.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
    [brio105-sensor-clip-v1.0.scad, brio105-sensor-clip-v1.0.stl, brio105-sensor-clip-v1.1.scad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]
2026-09-20 Reorganise into hardware/; add wiring docs, the enclosure and board tests
    Root went from 19 entries to 4. Everything printable or electrical now sits
    under hardware/, with one folder per part, and each part documents itself.
    hardware/clip/ v1.0-v1.2 + the tape-measure photo, and a README
    holding the version comparison and print orientation
    hardware/enclosure/ the XIAO ESP32-C6 desk box, tray and lid STLs, and
    the KiCad-derived board model
    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
    [brio100-camera-head.stl, brio100-monitor-clip.stl, brio105-sensor-clip-v1.0.scad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]
